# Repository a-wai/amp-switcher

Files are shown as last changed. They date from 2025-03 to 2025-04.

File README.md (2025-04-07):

# Amp Switcher

Table of contents:
* [Relays Array](#relays-array)
* [Control Matrix](#control-matrix)
* [Building](#building)
* [Licensing](#licensing)

---

The Amp Switcher is a device for easily switching between (guitar) amplifiers
when a single speaker cabinet is used and/or available.

It is designed so that, at any given moment:
* the guitar input is routed to the selected amp (and only this one!)
* the selected amp's output (and only this one!) is routed to the cab
* all unused amps have their input muted ("shorted" in electrical terms)
* all unused amps have a dummy (resistive) load connected to their speaker
  output

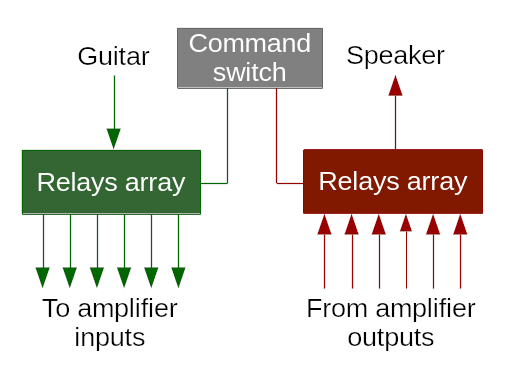
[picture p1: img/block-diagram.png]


Note: this repository only includes the electronics schematics and PCB designs.
Mechanical design and building is left to the reader's skills and imagination.

## Relays Array

This is the part responsible for the actual switching. In order to minimize the
number of different parts needed, this PCB is meant to be "universal", in the
sense that it can be used both for the "Guitar -> Amp Inputs" section (with an
optional built-in buffer) and for the "Amp Outputs -> Speaker Cab" one.

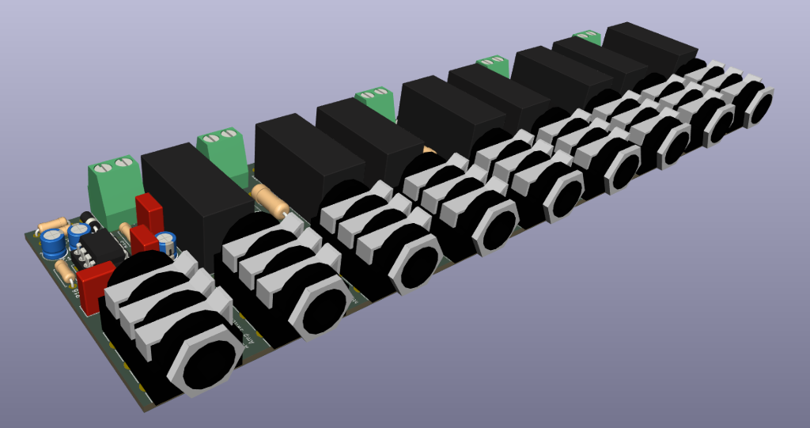
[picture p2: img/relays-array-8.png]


The board should be populated differently depending on the intended function:
* for a speaker out board, the 2W resistors (R1-R8) should be populated,
  especially when used with tube amplifiers
* guitar in boards shouldn't include those resistors, but instead the
  corresponding solder jumpers should be bridged by applying solder across them

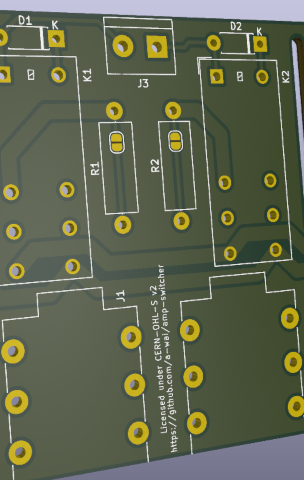
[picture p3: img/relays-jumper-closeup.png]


The input/output section (part of the PCB on the left of J1 & K1) can also be
used in 4 different ways:
* external connector, direct routing: do not populate any component except J10
  (+12V) and **J15** (to/from external connector)
* on-board jack connector, direct routing (recommended for speaker out board):
  populate only J14 and J10, and (generously) apply solder across JPX1
* external connector, input buffer (only suitable for "guitar input" board): do
  not populate any component except J10 (+12V) and **J16** (to/from external
  connector)
* on-board jack connector, input buffer (only suitable for "guitar input"
  board): populate all components except J15 and J16

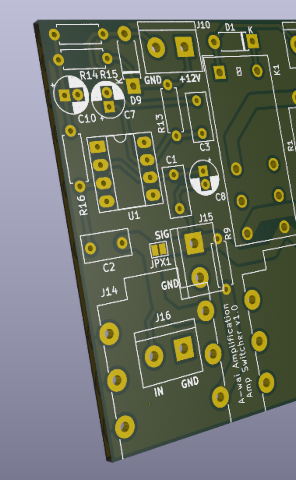
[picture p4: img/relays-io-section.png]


Finally, the PCB is split in blocks of 2 relays, with oblong holes in the board
so it can easily be broken to only keep the needed number of I/Os. This allows
the same design to be used in projects of different sizes. Of course, you can
avoid wasting material by using the properly-sized PCB: we provide design and
Gerber files for variants with 2, 4, 6 or 8 relays.

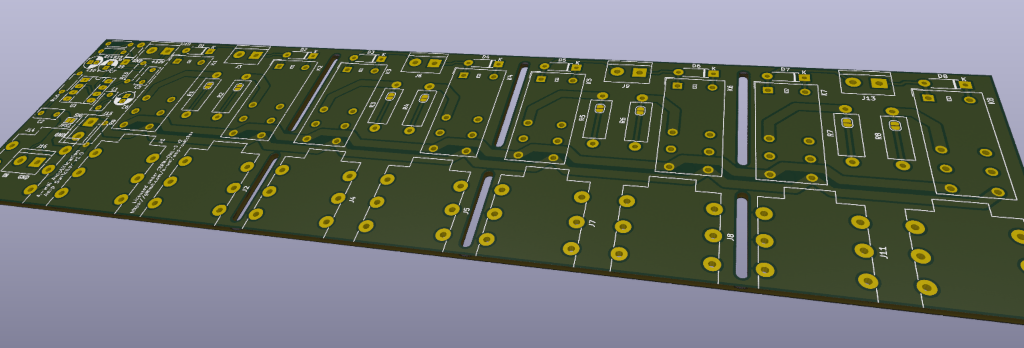
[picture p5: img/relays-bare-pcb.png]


**WARNING: although using relatively wide (2mm) PCB tracks, we recommend the
boards to be manufactured with 2oz copper weight if they are to be used with
amplifiers above 20W RMS of nominal output power.**

## Control Matrix

The control board is kept as simple as possible: it is made of a single rotary
switch, with as many LEDs as needed to indicate the currently selected amp. The
first switch position (fully counter-clockwise) is the OFF position where no
amplifier is selected; turning the switch clockwise will select amplifiers one
after another, lighting the corresponding LED on (the first being D1 -- the
leftmost one -- then D2, D3 and so on...).

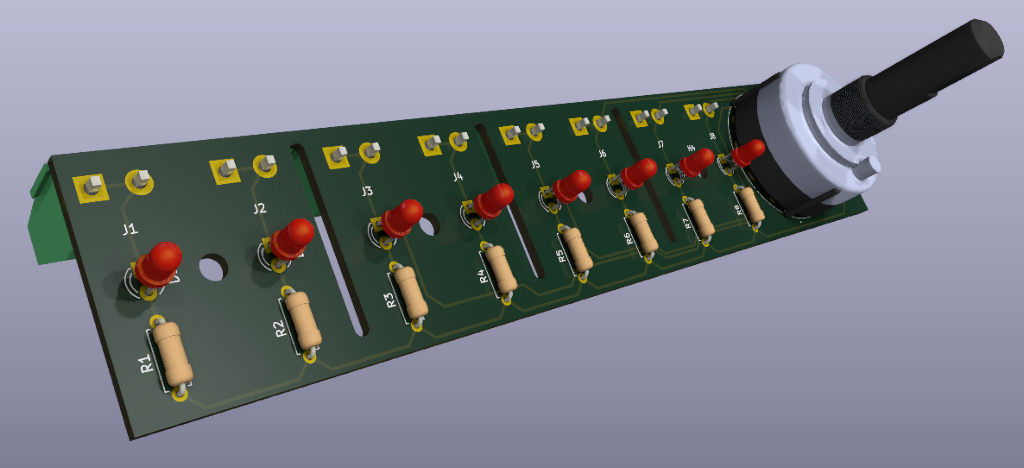
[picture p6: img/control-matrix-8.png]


This PCB is meant to be mounted directly on the front panel, with screw
terminals on the opposite side of the board for connecting to the corresponding
terminals of the "Relays Array" boards. Like the latter, it also includes
oblong holes for easily resizing the PCB to your needs (watch out for
[#1](https://github.com/a-wai/amp-switcher/issues/1) though), and we still
provide design and Gerber files for 2/4/6/8-way variants.

Finally, a simpler (and more compact) version is also provided for 2-way
devices, using a smaller ON-OFF-ON toggle switch instead of the rotary one.

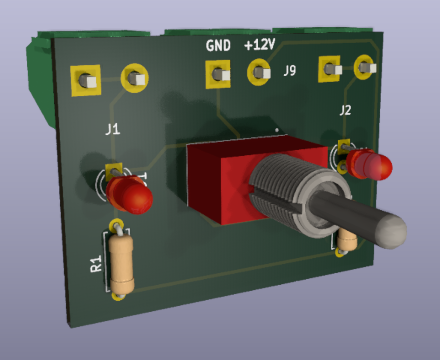
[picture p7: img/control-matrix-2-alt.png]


*Note: those familiar with matrices will likely notice the "Control Matrix"
naming isn't really accurate, as a 1xN matrix is basically an array, just like
the "Relays Array" board is; however I didn't want to use "array" in both
boards' names, and I think it sounds better that way anyway* 😉

## Building

This project was kindly sponsored by [PCBWay](https://www.pcbway.com) who
provided PCBs for the prototype builds free of charge, many thanks to them!
Moreover, working with this company has been a really nice experience:
* the ordering process was as easy as it gets (upload Gerber files, select
  features, place order, and that's it!)
* build time was 3-4 days as announced at order time (they also offer "express"
  options for an additional fee)
* quality and finish are both excellent! 👍

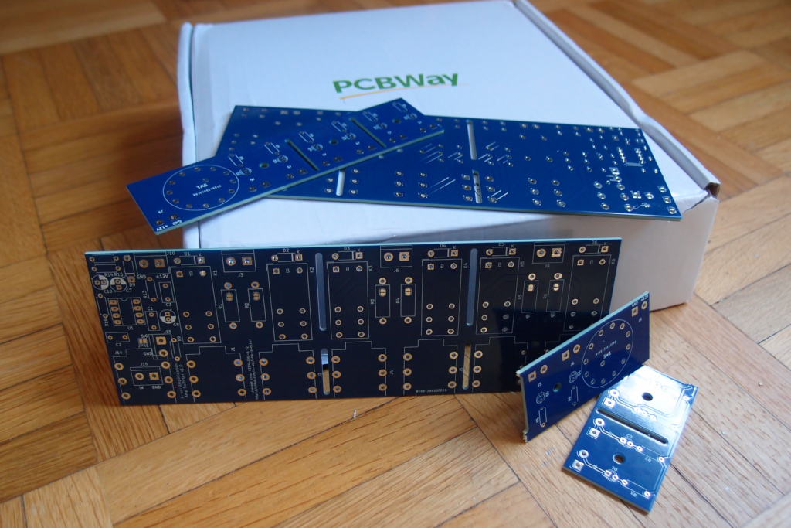
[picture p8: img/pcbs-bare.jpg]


When populating the boards, one should place and solder the components in the
following order:

1. Jumpers as needed (R1-R8 on the input board, JPX1 on the output one -- and
   on the input board **when not wiring the optional buffer**)
1. Diodes & low-wattage resistors
1. *Input board w/ buffer only:* DIP-8 socket & 100 nF capacitors
1. Screw terminals
1. *Input board w/ buffer only:* electrolytic capacitors
1. Relays & jack connectors
1. *Output board only:* 2W resistors; keeping the resistors' bodies away from
   the board is a good idea in case things go wrong: only the resistor will
   burn, not the PCB!

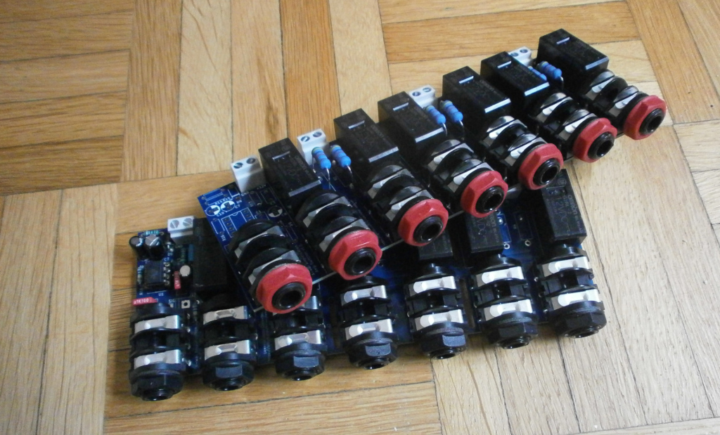
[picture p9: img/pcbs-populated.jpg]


For the control matrix board, resistors should be mounted first, then the
rotary switch. The LEDs are first mounted on the front panel, then soldered
after putting the board in place (this can be tricky, but is feasible).

A few additional notes:

* R1-R8 values should be tweaked depending on the LEDs used, especially when
  using various colors (e.g. 10k could work fine for blue LEDs, 5.1k for orange
  ones, and 47k for "warm white" LEDs)
* the GND post of the output board should remain unconnected
* on this same board, the jumper connecting the ground plane to the GND signal
  should be cut (this will probably be converted to an open solder jumper soon)

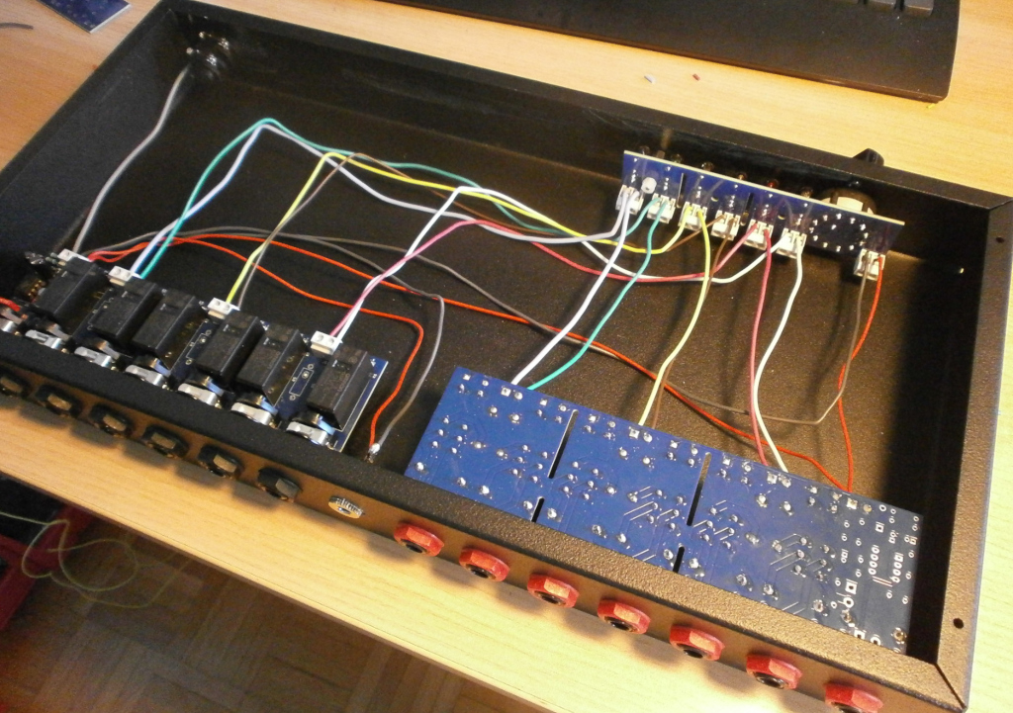
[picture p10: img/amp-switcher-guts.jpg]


Once all the boards are in place (but not fully secured yet), one just has to
run the wires to/from the appropriate solder terminals and the DC input
connector. Here, using wires of various different colors is an efficient way
not to get lost and ensure the wiring is correct.

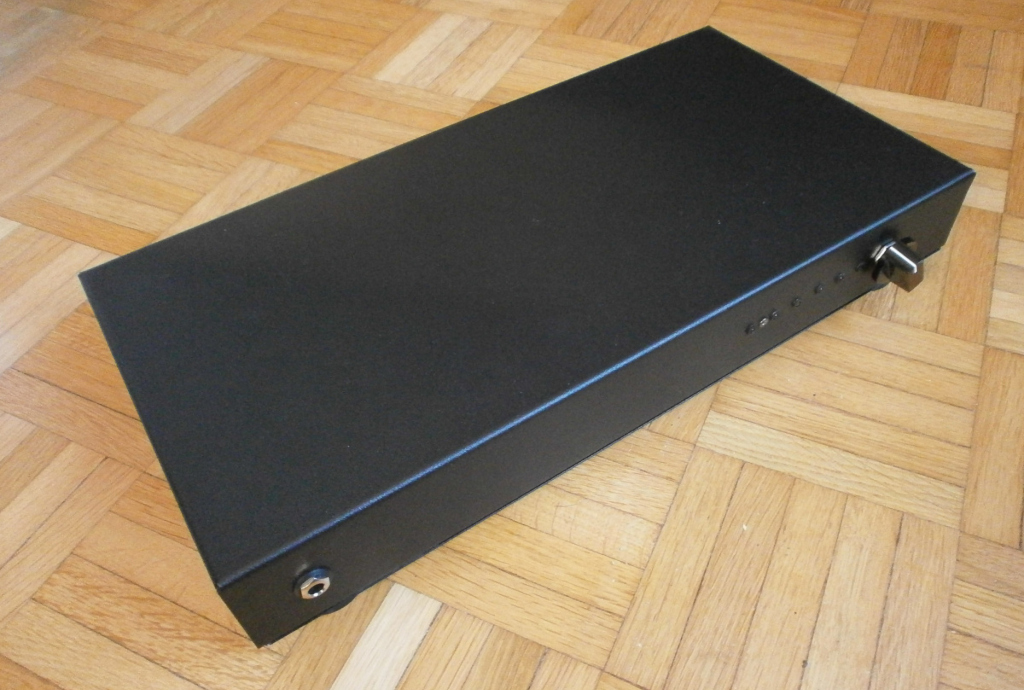
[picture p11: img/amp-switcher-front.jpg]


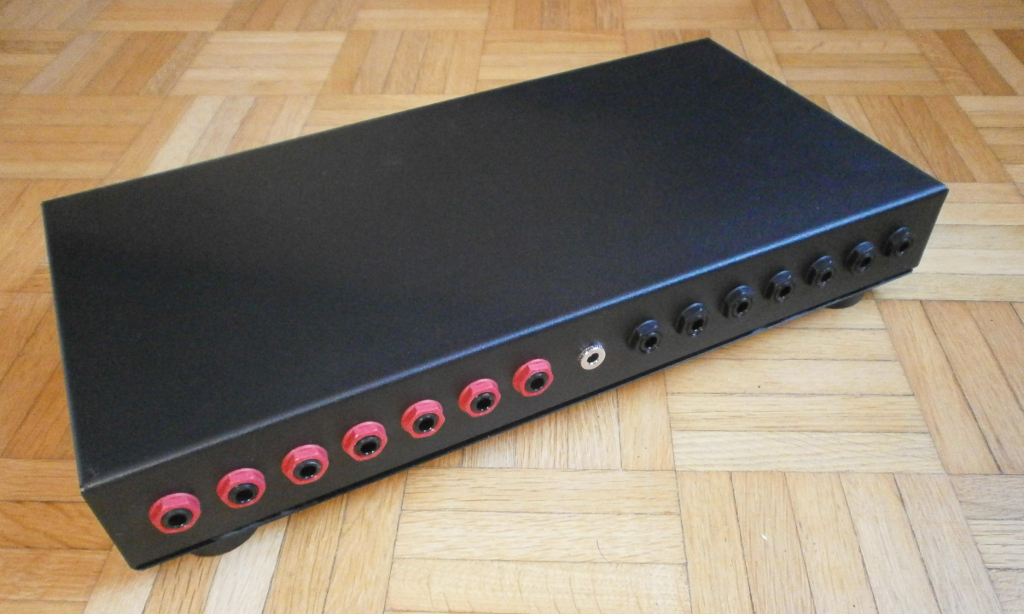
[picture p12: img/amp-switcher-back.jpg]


## Licensing

Copyright 2025 Arnaud Ferraris.

3D models for the Neutrik jacks are © Inventor eFX Technology and have been
downloaded from https://www.inventfx.com/_ifxkicad/_ifxkicadxtra.htm

3D models for the rotary and toggle switches aren't included due to licensing
restrictions, but they can be downloaded from https://componentsearchengine.com
* [CK1049](https://componentsearchengine.com/part-view/CK1049/Lorlin) rotary
  switch
* [A105SYZQ04](https://componentsearchengine.com/part-view/A105SYZQ04/TE%20Connectivity)
  toggle switch

This source describes Open Hardware and is licensed under the CERN-OHL-S v2.

You may redistribute and modify this source and make products using it
under the terms of the CERN-OHL-S v2 (https://ohwr.org/cern_ohl_s_v2.txt).

This source is distributed WITHOUT ANY EXPRESS OR IMPLIED WARRANTY, INCLUDING
OF MERCHANTABILITY, SATISFACTORY QUALITY AND FITNESS FOR A PARTICULAR PURPOSE.
Please see the CERN-OHL-S v2 for applicable conditions.

Source location: https://github.com/a-wai/amp-switcher

As per CERN-OHL-S v2 section 4, should You produce hardware based on this
source, You must where practicable maintain the Source Location visible on the
PCBs and user documentation of the Amp Switcher or other products you make
using this source.

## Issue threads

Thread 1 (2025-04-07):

Control PCB may require additional wiring when resized

a-wai, 2025-04-07:
When resizing the control PCB, we start by removing positions 2 & 3 (with pos 1 being OFF), then pos 4 & 5 and so on. This might require additional wiring when using a 3/4/6-positions switch due to shortening the board.

For example, when using the 6-way PCB resized to only 2 "slots" with a 3P4T rotary switch, the following has to be done:
* solder a wire between the switch pins #2 and #6
* solder a wire between the switch pins #3 and #7

This should be fixed by moving the rotary switch to the left side of the board (instead of the right as is currently the case). This will allow to keep the same "logic" (turn clockwise to select amps from left to right) but will ensure the 1st position is the closest to the switch, getting rid of the need for additional wiring.

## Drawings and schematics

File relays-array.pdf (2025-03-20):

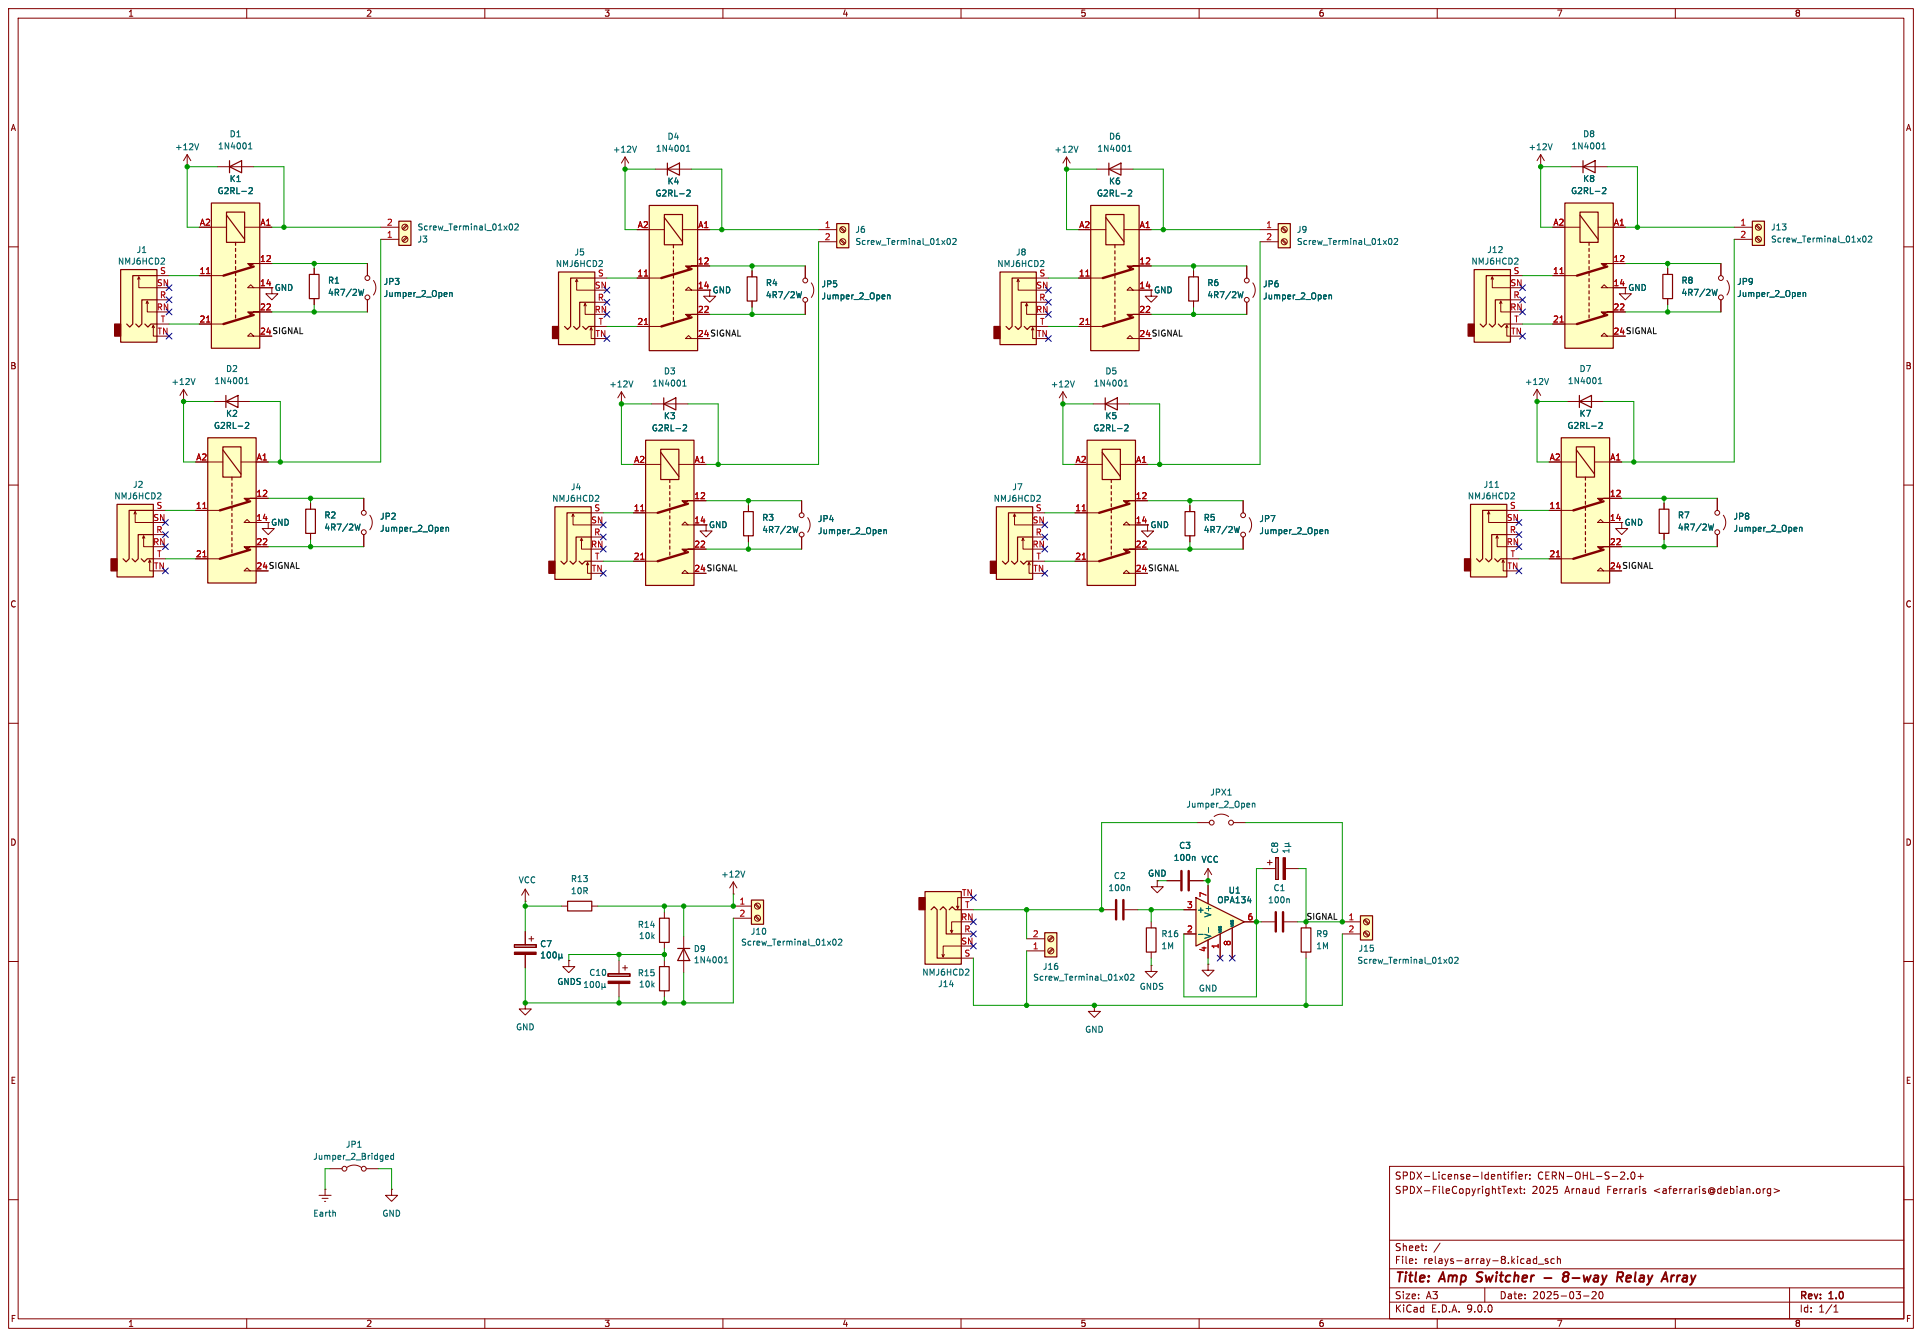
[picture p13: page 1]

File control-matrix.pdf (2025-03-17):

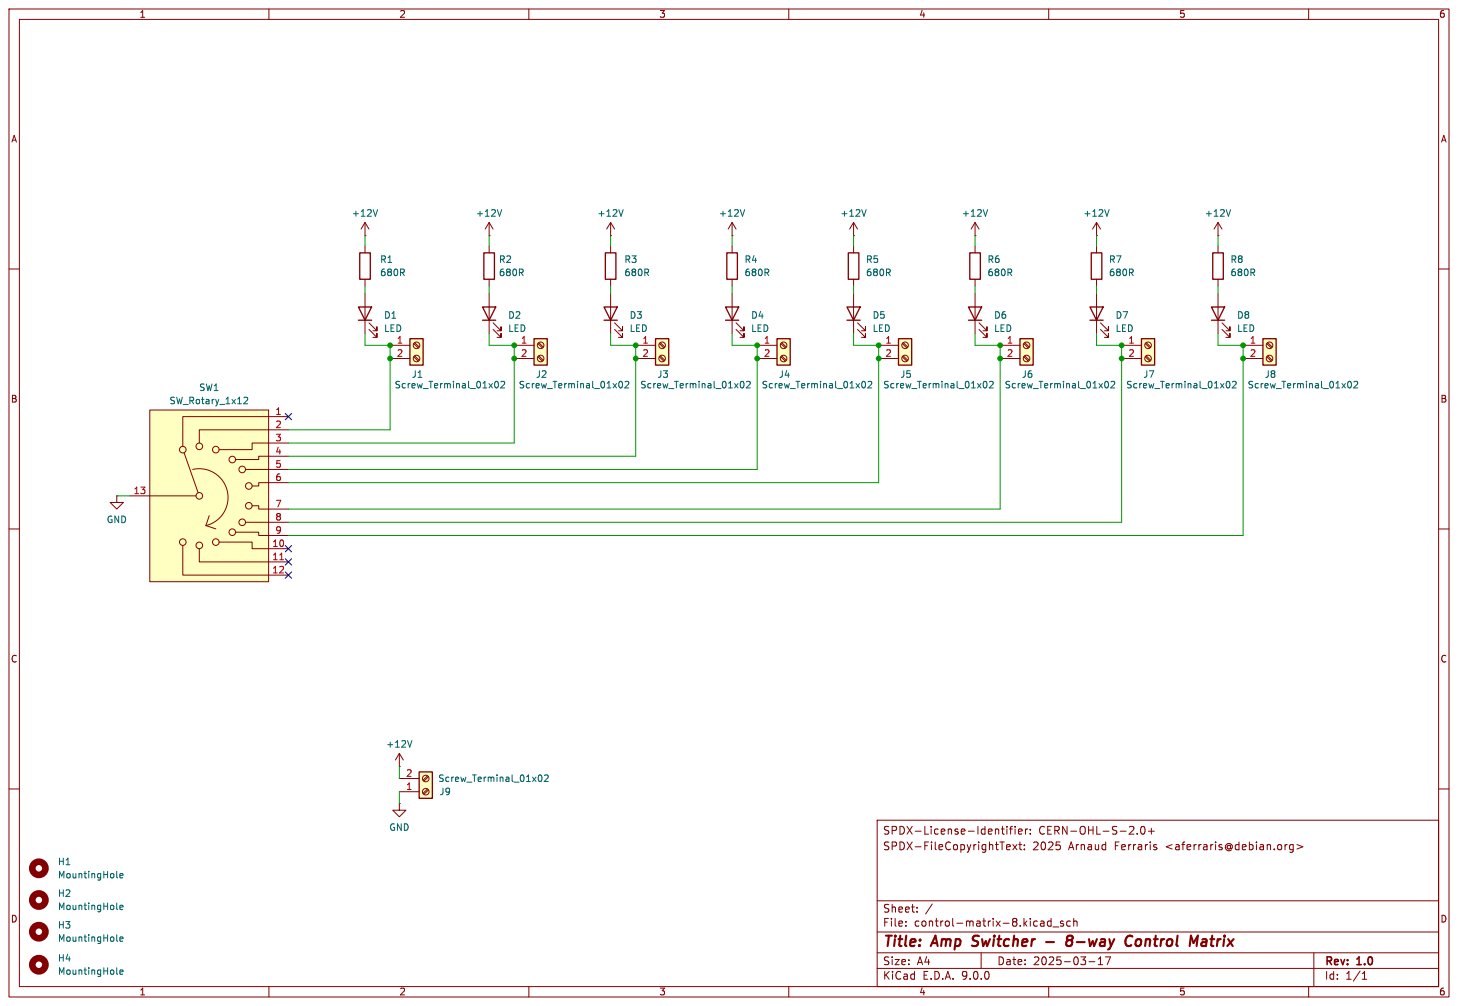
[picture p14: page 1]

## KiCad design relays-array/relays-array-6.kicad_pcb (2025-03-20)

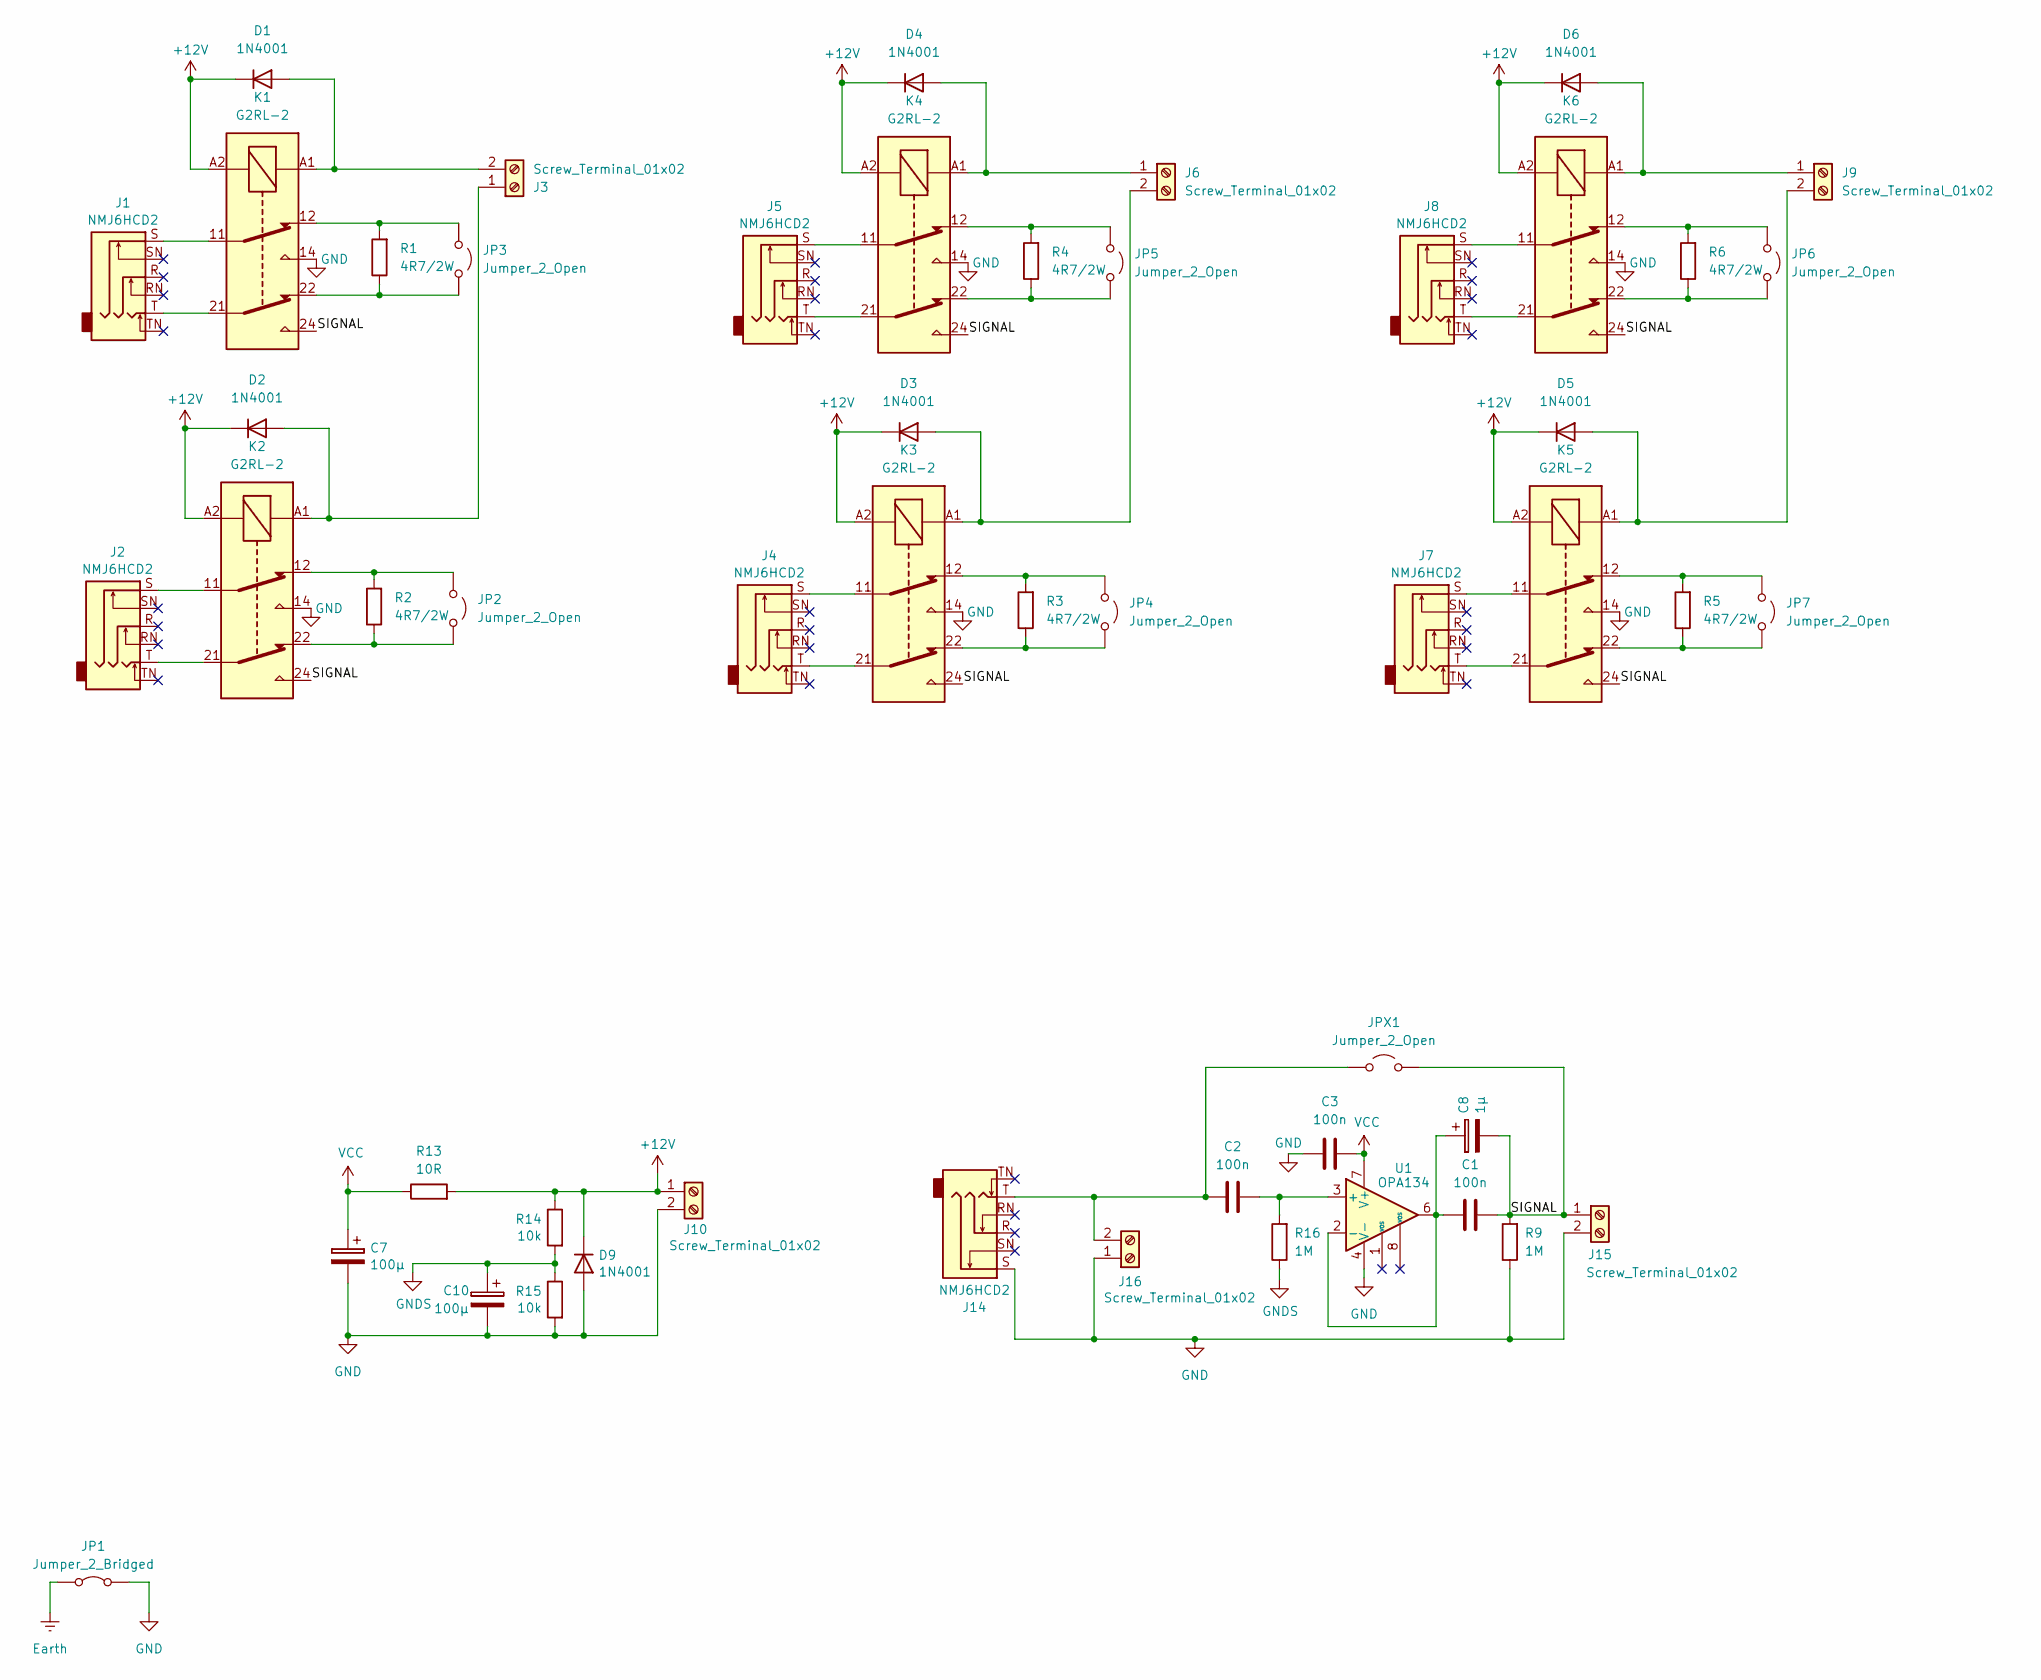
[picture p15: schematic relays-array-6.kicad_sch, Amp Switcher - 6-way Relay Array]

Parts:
C1, C2, C3: 100n; C_Rect_L7.2mm_W3.5mm_P5.00mm_FKS2_FKP2_MKS2_MKP2
C7: 100µ; CP_Radial_D5.0mm_P2.00mm
C8: 1µ; CP_Radial_D5.0mm_P2.00mm
C10: 100µ; CP_Radial_D5.0mm_P2.00mm; MPN FW
D1, D2, D3, D4, D5, D6, D9: 1N4001; D_DO-41_SOD81_P7.62mm_Horizontal
J1, J2, J4, J5, J7, J8, J14: NMJ6HCD2; Jack_6.35mm_Neutrik_NMJ6HCD2_Horizontal
J3, J6, J9, J10, J15, J16: Screw_Terminal_01x02; TerminalBlock_bornier-2_P5.08mm
JP1: Jumper_2_Bridged; SolderJumper-2_P1.3mm_Bridged_RoundedPad1.0x1.5mm
JP2, JP3, JP4, JP5, JP6, JP7: Jumper_2_Open; SolderJumper-2_P1.3mm_Open_RoundedPad1.0x1.5mm
JPX1: Jumper_2_Open; SolderJumper-2_P1.3mm_Open_Pad1.0x1.5mm
K1, K2, K3, K4, K5, K6: G2RL-2; Relay_DPDT_Omron_G2RL-2
R1, R2, R3, R4, R5, R6: 4R7/2W; R_Axial_DIN0414_L11.9mm_D4.5mm_P15.24mm_Horizontal
R9, R16: 1M; R_Axial_DIN0207_L6.3mm_D2.5mm_P7.62mm_Horizontal
R13: 10R; R_Axial_DIN0207_L6.3mm_D2.5mm_P7.62mm_Horizontal
R14, R15: 10k; R_Axial_DIN0207_L6.3mm_D2.5mm_P7.62mm_Horizontal
U1: OPA134; DIP-8_W7.62mm_Socket_LongPads

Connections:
+12V: D1.1 (K), D2.1 (K), D3.1 (K), D4.1 (K), D5.1 (K), D6.1 (K), D9.1 (K), J10.1, K1.A2, K2.A2, K3.A2, K4.A2, K5.A2, K6.A2, R13.2, R14.1
/SIGNAL: C1.1, C8.2, J15.1, JPX1.1 (A), K1.24, K2.24, K3.24, K4.24, K5.24, K6.24, R9.2
Earth: JP1.1 (A)
GND: C3.2, C7.2, C10.2, D9.2 (A), J10.2, J14.S, J15.2, J16.1, JP1.2 (B), K1.14, K2.14, K3.14, K4.14, K5.14, K6.14, R9.1, R15.2, U1.4 (V-)
GNDS: C10.1, R14.2, R15.1, R16.1
unnamed: D1.2 (A), J3.2, K1.A1
unnamed: D2.2 (A), J3.1, K2.A1
unnamed: D3.2 (A), J6.2, K3.A1
unnamed: D4.2 (A), J6.1, K4.A1
unnamed: D5.2 (A), J9.2, K5.A1
unnamed: D6.2 (A), J9.1, K6.A1
unnamed: J1.S, K1.11
unnamed: J1.T, K1.21
unnamed: J2.S, K2.11
unnamed: J2.T, K2.21
unnamed: J4.S, K3.11
unnamed: J4.T, K3.21
unnamed: J5.S, K4.11
unnamed: J5.T, K4.21
unnamed: J7.S, K5.11
unnamed: J7.T, K5.21
unnamed: J8.S, K6.11
unnamed: J8.T, K6.21
unnamed: C2.2, J14.T, J16.2, JPX1.2 (B)
unnamed: JP2.1 (A), K2.12, R2.2
unnamed: JP2.2 (B), K2.22, R2.1
unnamed: JP3.1 (A), K1.12, R1.2
unnamed: JP3.2 (B), K1.22, R1.1
unnamed: JP4.1 (A), K3.12, R3.2
unnamed: JP4.2 (B), K3.22, R3.1
unnamed: JP5.1 (A), K4.12, R4.2
unnamed: JP5.2 (B), K4.22, R4.1
unnamed: JP6.1 (A), K6.12, R6.2
unnamed: JP6.2 (B), K6.22, R6.1
unnamed: JP7.1 (A), K5.12, R5.2
unnamed: JP7.2 (B), K5.22, R5.1
unnamed: C2.1, R16.2, U1.3 (+)
unnamed: C1.2, C8.1, U1.2 (-), U1.6
VCC: C3.1, C7.1, R13.1, U1.7 (V+)

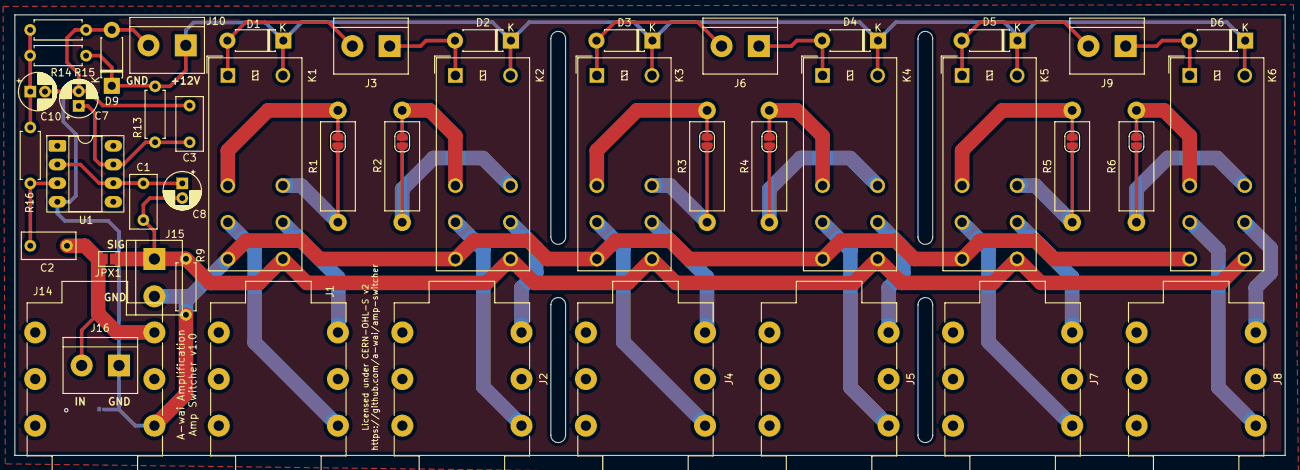
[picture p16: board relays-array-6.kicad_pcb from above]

Board: 2 copper layers, 173.0 x 60.0 mm, 52 parts (1 on the bottom side), 38 nets.

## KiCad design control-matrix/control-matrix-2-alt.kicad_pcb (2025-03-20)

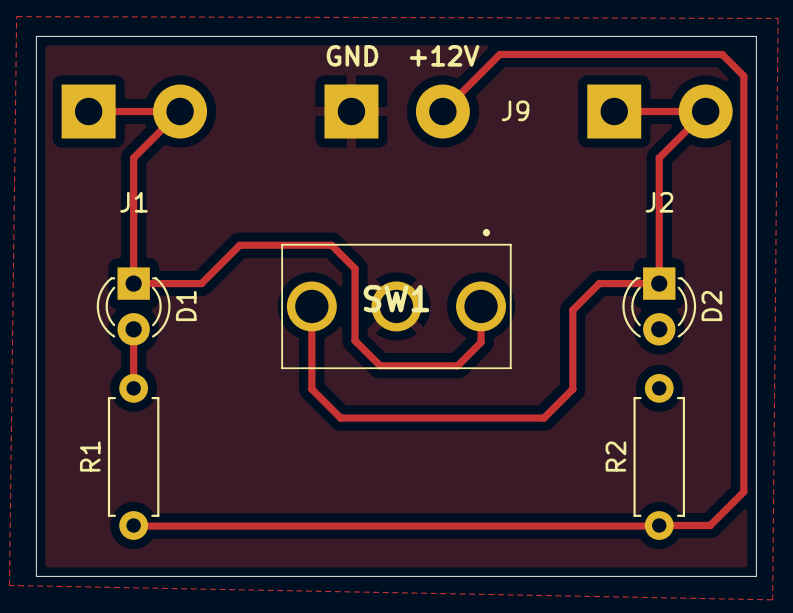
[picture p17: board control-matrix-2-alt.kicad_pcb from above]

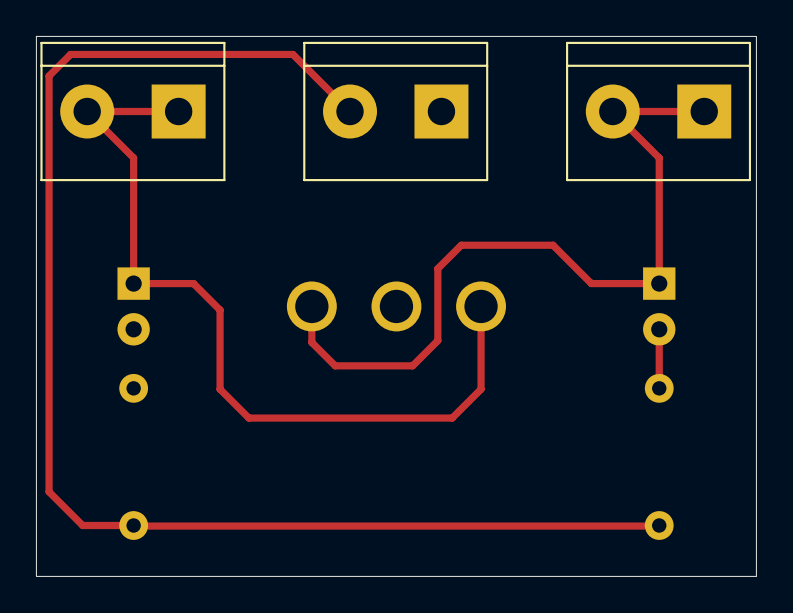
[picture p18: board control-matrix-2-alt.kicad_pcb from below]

Board: 2 copper layers, 40.0 x 30.0 mm, 8 parts (3 on the bottom side), 6 nets.

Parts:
D1, D2: LED; LED_D3.0mm
J1, J2, J9: Screw_Terminal_01x02; TerminalBlock_bornier-2_P5.08mm
R1, R2: 680R; R_Axial_DIN0207_L6.3mm_D2.5mm_P7.62mm_Horizontal
SW1: SW_SPDT; SPDT_Toggle

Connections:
+12V: J9.2, R1.1, R2.1
GND: J9.1, SW1.2 (B)
unnamed: D1.2 (A), R1.2
unnamed: D1.1 (K), J1.1, J1.2, SW1.1 (A)
unnamed: D2.2 (A), R2.2
unnamed: D2.1 (K), J2.1, J2.2, SW1.3 (C)

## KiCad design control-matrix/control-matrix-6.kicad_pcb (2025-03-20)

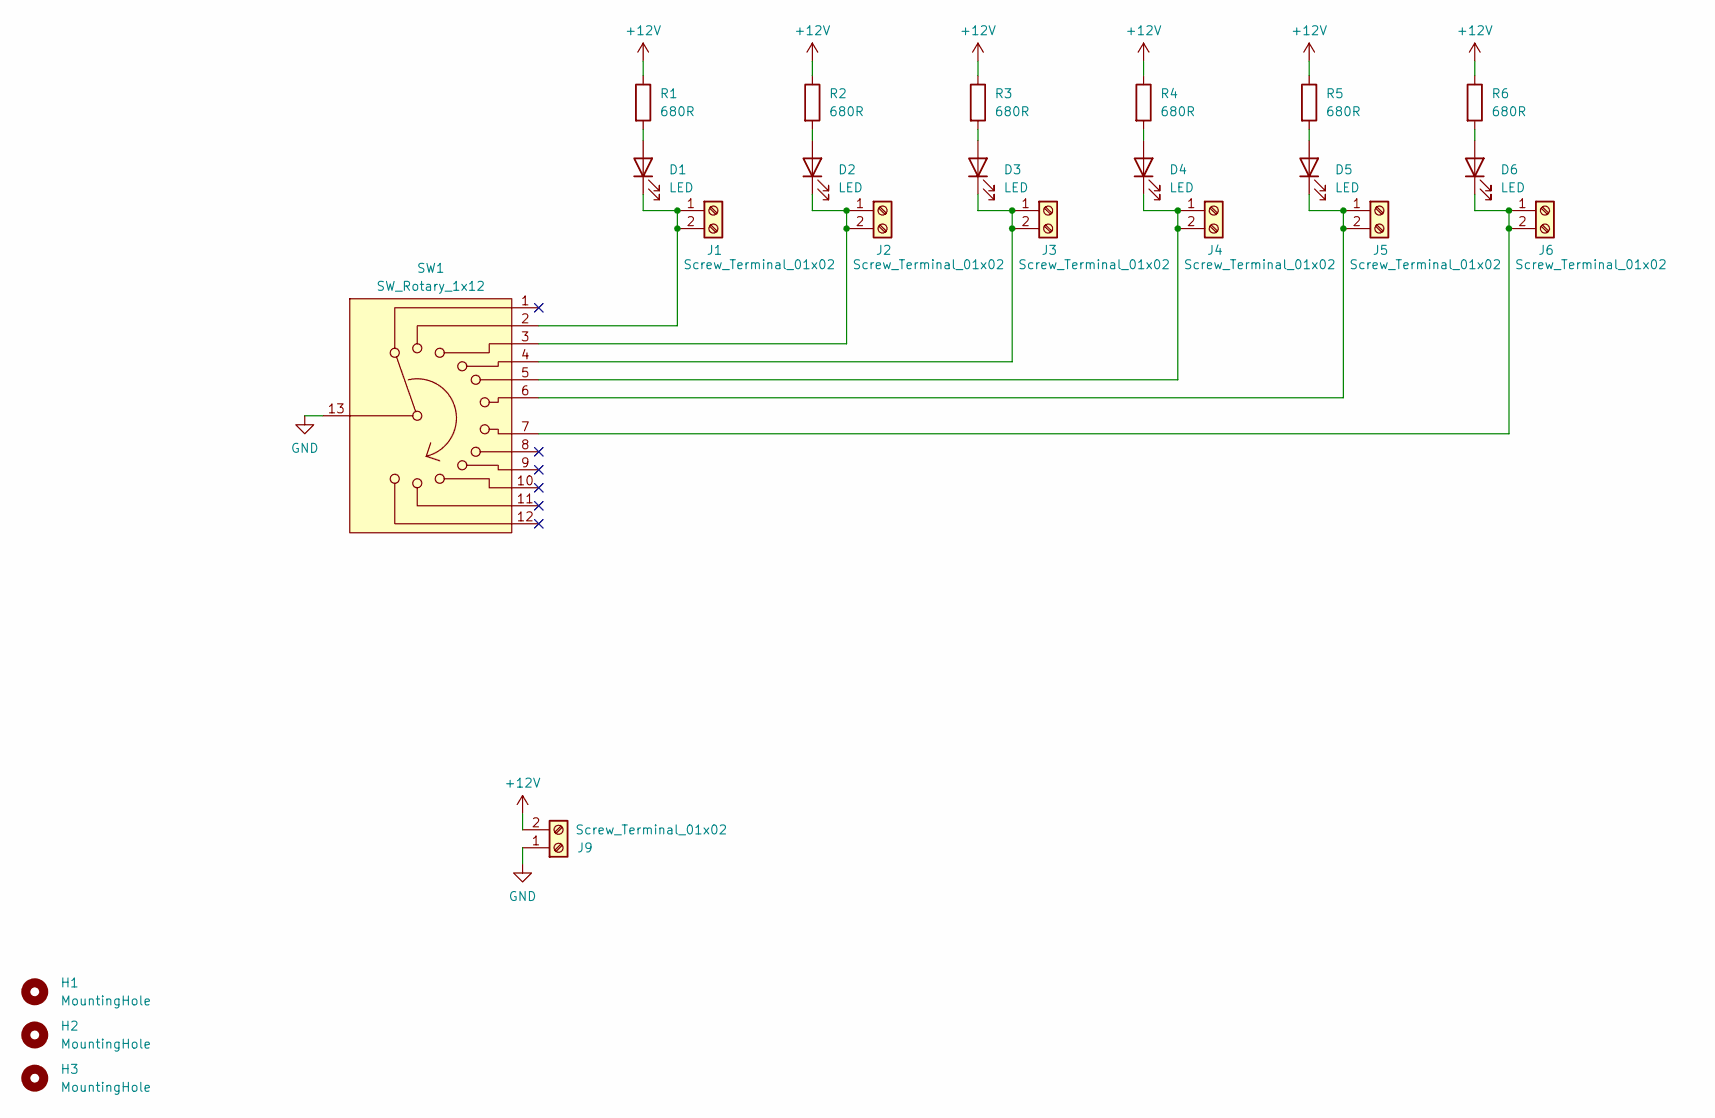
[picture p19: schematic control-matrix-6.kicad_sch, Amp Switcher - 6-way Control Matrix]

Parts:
D1, D2, D3, D4, D5, D6: LED; LED_D3.0mm
H1, H2, H3: MountingHole; MountingHole_3.2mm_M3
J1, J2, J3, J4, J5, J6, J9: Screw_Terminal_01x02; TerminalBlock_bornier-2_P5.08mm
R1, R2, R3, R4, R5, R6: 680R; R_Axial_DIN0207_L6.3mm_D2.5mm_P7.62mm_Horizontal
SW1: SW_Rotary_1x12; CK1059

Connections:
+12V: J9.2, R1.1, R2.1, R3.1, R4.1, R5.1, R6.1
GND: J9.1, SW1.13
unnamed: D1.2 (A), R1.2
unnamed: D1.1 (K), J1.1, J1.2, SW1.2
unnamed: D2.2 (A), R2.2
unnamed: D2.1 (K), J2.1, J2.2, SW1.3
unnamed: D3.2 (A), R3.2
unnamed: D3.1 (K), J3.1, J3.2, SW1.4
unnamed: D4.2 (A), R4.2
unnamed: D4.1 (K), J4.1, J4.2, SW1.5
unnamed: D5.2 (A), R5.2
unnamed: D5.1 (K), J5.1, J5.2, SW1.6
unnamed: D6.2 (A), R6.2
unnamed: D6.1 (K), J6.1, J6.2, SW1.7

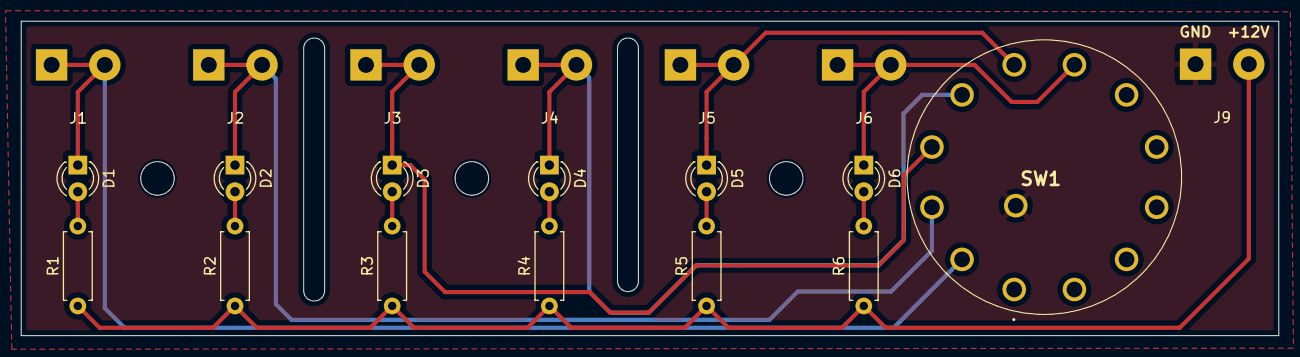
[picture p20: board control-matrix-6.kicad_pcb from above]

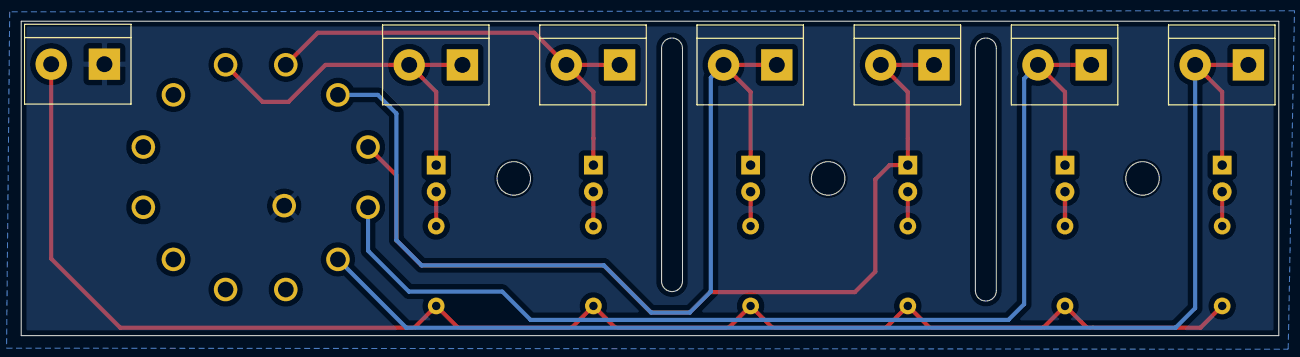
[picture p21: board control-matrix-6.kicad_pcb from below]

Board: 2 copper layers, 120.0 x 30.0 mm, 23 parts (7 on the bottom side), 14 nets.

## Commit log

2025-03-12 relays-array: add actual DIP-8 device on socket
    [relays-array-8.kicad_pcb]
2025-03-12 relays-array: add 2/4/6-relays variants
    [relays-array-2-B_Cu.gbl, relays-array-2-B_Mask.gbs, relays-array-2-Edge_Cuts.gm1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]
2025-03-12 relays-array: add terminal block for buffer use w/ external connector
    [relays-array-2-B_Cu.gbl, relays-array-2-B_Mask.gbs, relays-array-2-Edge_Cuts.gm1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]
2025-03-17 Add control-matrix boards for 2/4/6/8-way devices
    [control-matrix-2-B_Cu.gbl, control-matrix-2-B_Mask.gbs, control-matrix-2-Edge_Cuts.gm1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]
2025-03-17 control-matrix: add smaller alternate version for 2-way devices
    [control-matrix-2-alt-B_Cu.gbl, control-matrix-2-alt-B_Mask.gbs, control-matrix-2-alt-Edge_Cuts.gm1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]
2025-03-17 control-matrix: add power input labels on silkscreen
    [control-matrix-2-B_Cu.gbl, control-matrix-2-B_Mask.gbs, control-matrix-2-Edge_Cuts.gm1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]
2025-03-17 relays-array: add terminal block labels on silkscreen
    [relays-array-2-B_Cu.gbl, relays-array-2-B_Mask.gbs, relays-array-2-Edge_Cuts.gm1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]
2025-03-18 control-matrix: 2-alt: move switch to center of board
    [control-matrix-2-alt-B_Cu.gbl, control-matrix-2-alt-B_Mask.gbs, control-matrix-2-alt-Edge_Cuts.gm1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]
2025-03-20 control-matrix: add ground planes
    This avoids having to etch too much copper.
    [control-matrix-2-B_Cu.gbl, control-matrix-2-B_Mask.gbs, control-matrix-2-Edge_Cuts.gm1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]
2025-03-20 relays-array: fix schematics error and add ground plane
    The jack connectors are all (except for the buffer input) wired
    backwards, with the tip going to `GND` and the sleeve on `SIGNAL`, while
    it should be the other way around.
    While at it, improve a bit the PCB tracks and add a ground plane. The
    latter is only connected to `GND` in a single point in order to avoid
    ground loops and other unpleasant issues.
    [relays-array-2-B_Cu.gbl, relays-array-2-B_Mask.gbs, relays-array-2-Edge_Cuts.gm1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]
2025-04-07 README: add reference to the control board resizing issue

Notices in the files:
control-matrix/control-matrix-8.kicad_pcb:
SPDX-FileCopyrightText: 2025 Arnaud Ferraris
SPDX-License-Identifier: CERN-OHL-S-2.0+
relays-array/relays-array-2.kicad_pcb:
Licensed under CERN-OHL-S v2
